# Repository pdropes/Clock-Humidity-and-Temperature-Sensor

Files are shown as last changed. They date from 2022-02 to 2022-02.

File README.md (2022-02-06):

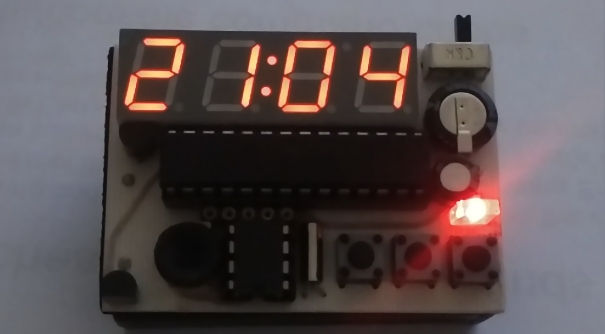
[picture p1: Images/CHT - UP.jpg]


# Clock, Humidity and Temperature Sensor
Relógio com medição de temperatura e humidade relativa

Descrição:
Pequeno aparelho portátil para visualização horária, temperatura e humidade relativa (alternadamente).
Já tinha trabalhado anteriormente com o sensor SHT21 da Sensirion, na construção de um controlador de estufa, é pequeno 3x3mm mas tem uma boa resolução (12/14bit for RH/T = RH0.04 & T0.01), apesar de fazer a leitura com esta precisão, uso aqui apenas uma casa decimal ás limitações do display.
Não foi implementado na programação medições de temperatura negativas, embora seja possível com outro tipo de display.
O sensor foi aqui montado numa placa á parte para minimizar a transferência térmica com a pcb principal (também sugerido na sua ficha técnica), entretanto a sua alimentação só é activada no momento das medições, reduz o consumo e tem maior precisão na leitura.
Desenho do circuito, fabrico da PCB, montagem e programação em 7 dias.

Caracteristicas:
- Microcontrolador atmega8 a 4MHz interno (não há necessidade de precisão aqui)
- Relógio RTC (PCF8563) com recurso a supercap 0.047F para retenção horária
- Possibilidade de acerto horário através dos switchs, modo ADC
- Sensor STH21 alimentado a 2.8V (VDD 2.1V to 3.6V), level shifter através de 2 BS170
- Consumo de 8 a 12mA (depende da intensidade do display)
- Brilho ajustável 

Programação: Bascom AVR, PCB: Eagle

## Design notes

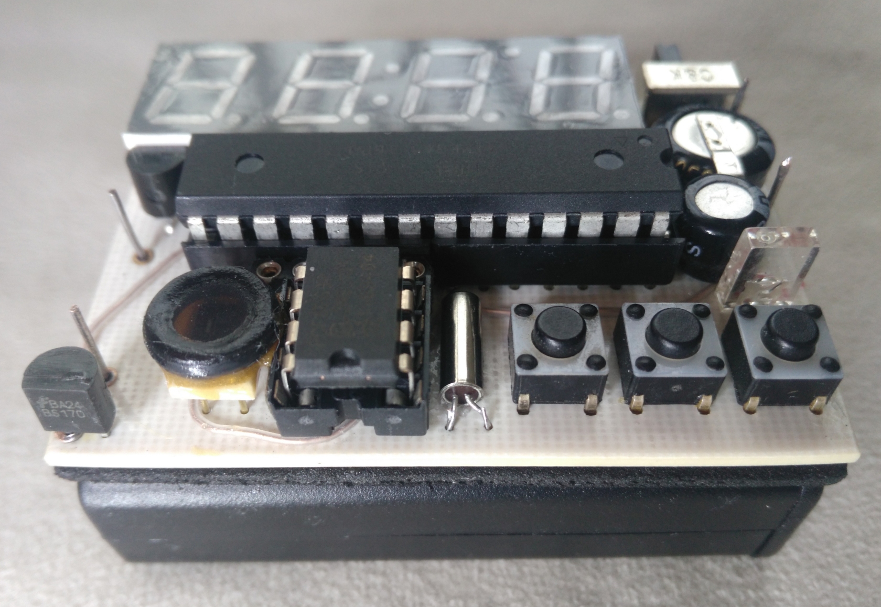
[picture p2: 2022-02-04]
Images/CTH - Filtro poeiras.jpg

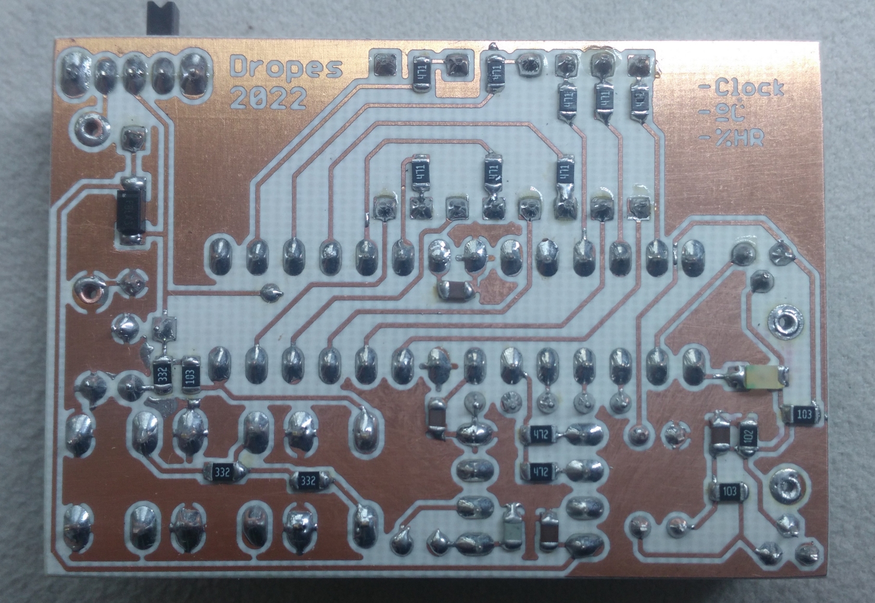
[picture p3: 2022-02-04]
Images/CTH - PCB SMDs.jpg

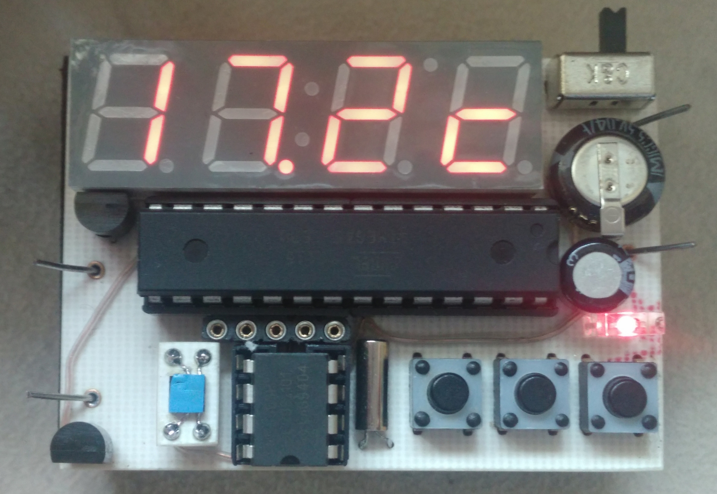
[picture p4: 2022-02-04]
Images/CTH - Funcionando.jpg

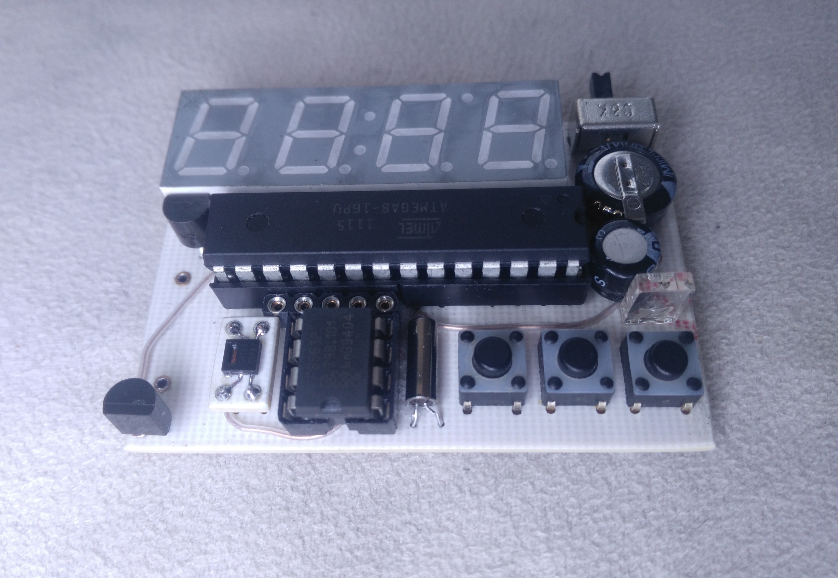
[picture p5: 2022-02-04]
Images/CTH - PCB TOP.jpg

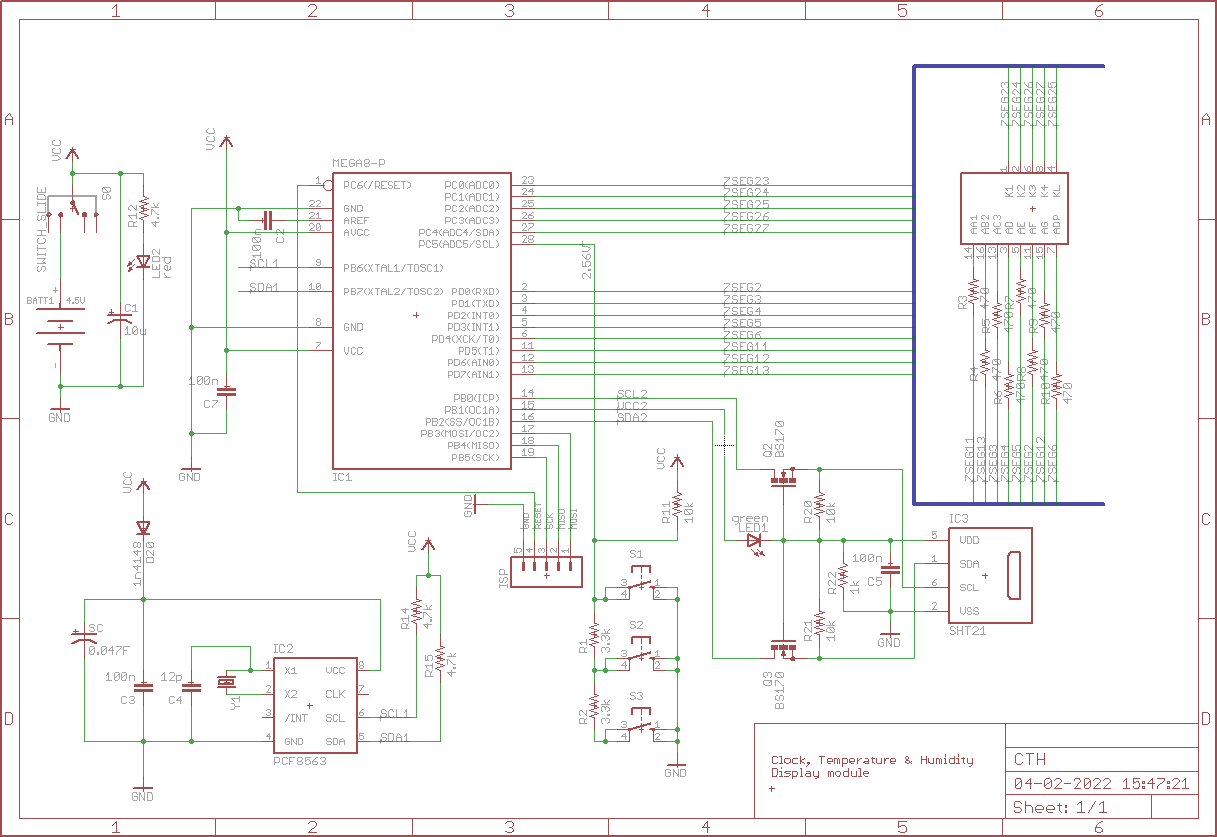
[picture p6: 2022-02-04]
Layout/CHT - Esquema.png

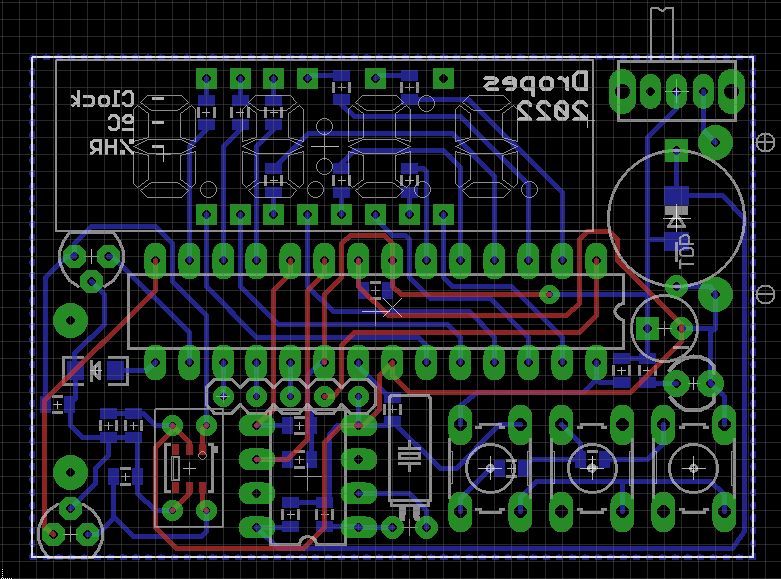
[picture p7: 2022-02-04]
Layout/CTH - PCB.png

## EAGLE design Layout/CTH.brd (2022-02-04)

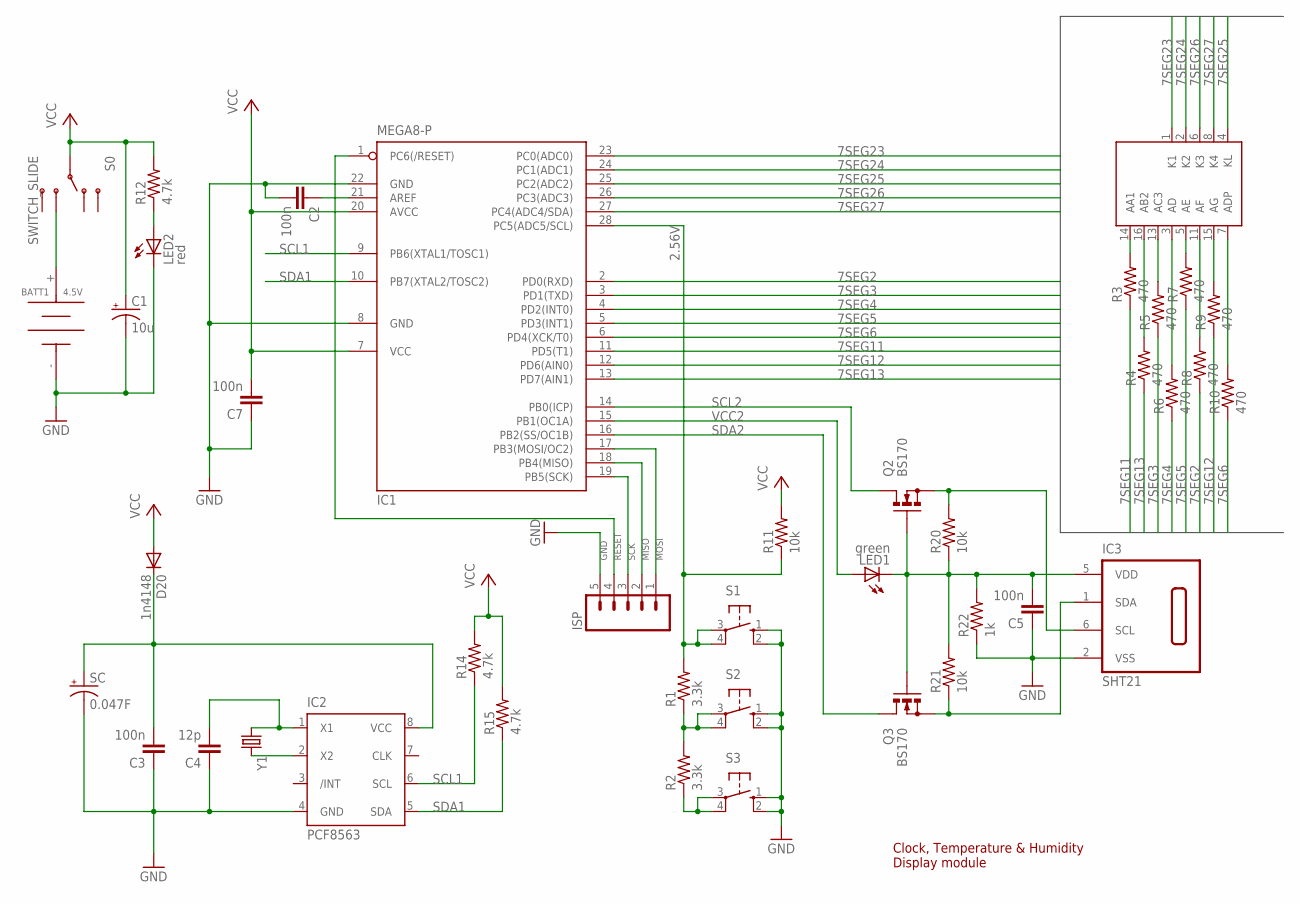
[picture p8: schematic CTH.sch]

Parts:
7SEG: LTC-4027JRLTC-4027JR; LTC-4727JR
BATT1: 1291-[2-56]; 1291
C1: 10u; CPOL-RADIAL-10UF-25V
C2, C3, C5, C7: 100n; 0805
C4: 12p; 0805
D20: 1n4148; SOD80C
IC1: MEGA8-P; DIL28-3
IC2: PCF8563; DS1307_PCF8583_DIL08
IC3: SHT21; DFN6/SHT
ISP: M05PTH; 1X05
LED1: green; SPARKFUN_LED-1206
LED2: red; LED3MM
Q2, Q3: BS170; SOT54E
R1, R2: 3.3k; 0805
R3, R4, R5, R6, R7, R8, R9, R10: 470; 0805
R11, R20, R21: 10k; 0805
R12, R14, R15: 4.7k; 0805
R22: 1k; 0805
S0: SWITCH_SLIDE
S1: 10-XX; B3F-10XX; MPN B3F-1000
S2, S3: 10-XX; B3F-10XX
SC: 0.047F; SUPERCAP_0.047F
Y1: CRYSTALTC38H; TC38H

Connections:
2.56V: IC1.28 (PC5(ADC5/SCL)), R1.2, R11.1, S1.3, S1.4 (P1)
7SEG2: IC1.2 (PD0(RXD)), R8.1
7SEG3: IC1.3 (PD1(TXD)), R5.1
7SEG4: IC1.4 (PD2(INT0)), R6.1
7SEG5: IC1.5 (PD3(INT1)), R7.1
7SEG6: IC1.6 (PD4(XCK/T0)), R10.1
7SEG11: IC1.11 (PD5(T1)), R3.1
7SEG12: IC1.12 (PD6(AIN0)), R9.1
7SEG13: IC1.13 (PD7(AIN1)), R4.1
7SEG23: 7SEG.1 (K1), IC1.23 (PC0(ADC0))
7SEG24: 7SEG.2 (K2), IC1.24 (PC1(ADC1))
7SEG25: 7SEG.4 (KL), IC1.25 (PC2(ADC2))
7SEG26: 7SEG.6 (K3), IC1.26 (PC3(ADC3))
7SEG27: 7SEG.8 (K4), IC1.27 (PC4(ADC4/SDA))
GND: BATT1.-, C1.2 (-), C2.2, C3.1, C4.1, C5.1, C7.1, IC1.8 (GND), IC1.22 (GND), IC2.4 (GND), IC3.2 (VSS), ISP.5, LED2.K (C), R22.1, S1.1 (S), S1.2 (S1), S2.1 (S), S2.2 (S1), S3.1 (S), S3.2 (S1), SC.2 (-)
MISO: IC1.18 (PB4(MISO)), ISP.2
MOSI: IC1.17 (PB3(MOSI/OC2)), ISP.1
unnamed: 7SEG.14 (AA1), R3.2
unnamed: 7SEG.16 (AB2), R4.2
unnamed: 7SEG.13 (AC3), R5.2
unnamed: BATT1.+, S0.E
unnamed: 7SEG.3 (AD), R6.2
unnamed: 7SEG.5 (AE), R7.2
unnamed: 7SEG.11 (AF), R8.2
unnamed: 7SEG.15 (AG), R9.2
unnamed: 7SEG.7 (ADP), R10.2
unnamed: IC2.2 (X2), Y1.2
unnamed: C2.1, IC1.21 (AREF)
unnamed: C5.2, IC3.5 (VDD), LED1.C, Q2.G, Q3.G, R20.1, R21.2, R22.2
unnamed: LED2.A, R12.1
unnamed: IC3.1 (SDA), Q3.S, R21.1
unnamed: R2.1, S3.3, S3.4 (P1)
unnamed: C4.2, IC2.1 (X1), Y1.1
unnamed: R1.1, R2.2, S2.3, S2.4 (P1)
unnamed: IC3.6 (SCL), Q2.S, R20.2
RESET: IC1.1 (PC6(/RESET)), ISP.4
SCK: IC1.19 (PB5(SCK)), ISP.3
SCL1: IC1.9 (PB6(XTAL1/TOSC1)), IC2.6 (SCL), R14.1
SCL2: IC1.14 (PB0(ICP)), Q2.D
SDA1: IC1.10 (PB7(XTAL2/TOSC2)), IC2.5 (SDA), R15.1
SDA2: IC1.16 (PB2(SS/OC1B)), Q3.D
VCC: C1.1 (+), C7.2, D20.A, IC1.7 (VCC), IC1.20 (AVCC), R11.2, R12.2, R14.2, R15.2, S0.M
VCC2: IC1.15 (PB1(OC1A)), LED1.A
VCC_RTC: C3.2, D20.C, IC2.8 (VCC), SC.1 (+)

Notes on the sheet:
Clock, Temperature & Humidity Display module

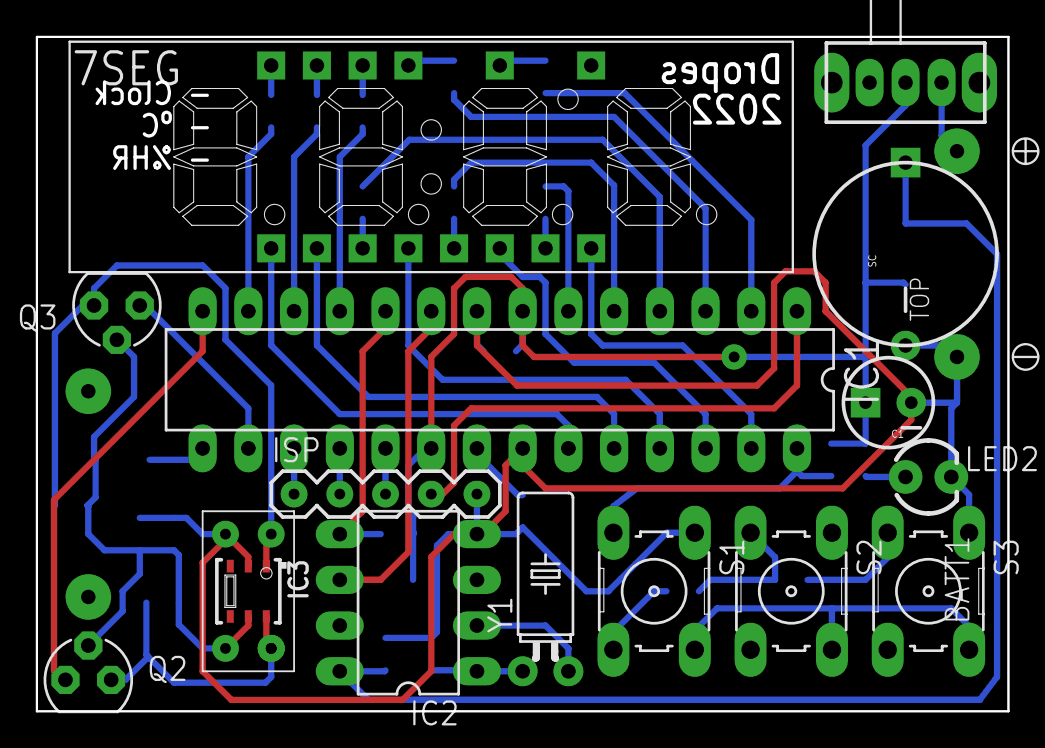
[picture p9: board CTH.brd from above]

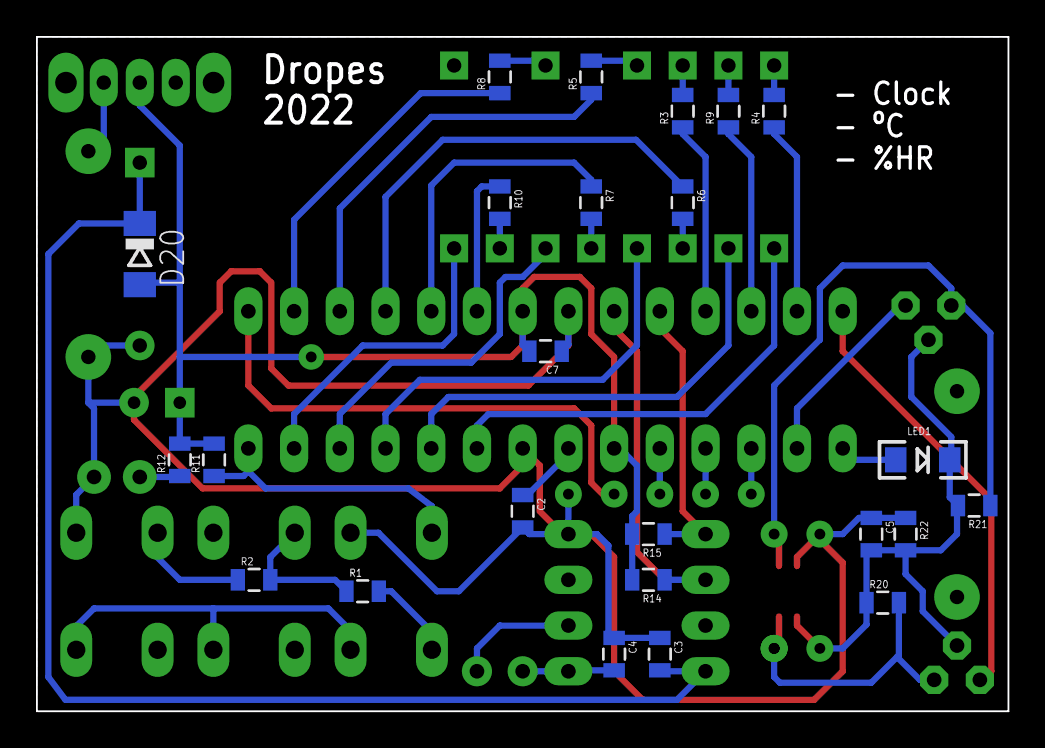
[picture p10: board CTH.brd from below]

Board: 2 copper layers, 54.0 x 37.5 mm, 40 parts (24 on the bottom side), 44 nets.

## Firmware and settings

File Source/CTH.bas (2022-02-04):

'#Dropes 02..03-02-2022
'clock - temperature - humidity
'Fuses: hfuse=D9 lfuse=E3

$regfile = "m8def.dat"
$crystal = 4000000

$hwstack = 32                                               ' default use 32 for the hardware stack
$swstack = 10                                               ' default use 10 for the SW stack
$framesize = 40                                             ' default use 40 for the frame space

'PIN        I/O   Func.      Func.
'09-PB6  O    SCL         RTC
'10-PB7  IO   SDA
'
'14.PB0  O    SCL2       SENSOR
'15.PB1  O    VCC2
'16.PB2  IO   SDA2

'23.PC0  O    7SEG_K1
'24.PC1  O    7SEG_K2
'25.PC2  O    7SEG_KL
'26.PC3  O    7SEG_K3
'27.PC4  O    7SEG_K4
'28.PC5  I      ADC5      SW1,2,3
'
'02.PD0  O     7SEG_F
'03.PD1  O     7SEG_C3
'04.PD2  O     7SEG_D
'05.PD3  O     7SEG_E
'06.PD4  O     7SEG_DP
'11.PD5  O     7SEG_A1
'12.PD6  O     7SEG_G
'13.PD7  O     7SEG_B2

'Digit nº
Ddrc = &B11011111
Portc = &B11011111
W1 Alias Portc.4
W2 Alias Portc.3
Col Alias Portc.2
W3 Alias Portc.1
W4 Alias Portc.0

'Segment
Ddrd = &B11111111
Portd = &B0

'I2C
Config Scl = Portb.6
Config Sda = Portb.7
Config I2cdelay = 10
I2cinit

'SHT21
Sht_on Alias Portb.1
Sht_sda_o Alias Portb.2
Sht_sda_i Alias Pinb.2
Sht_scl Alias Portb.0
Config Sht_on = Output
Config Sht_sda_o = Output
Config Sht_scl = Output

'3 SW  Open=1023 S1=0 S2=423 S3=678
Config Adc = Single , Prescaler = 8 , Reference = Internal
Enable Adc

'8 -bit Timer / Counter0
'Prescale:1,8,64,256 or 1024
Config Timer0 = Timer , Prescale = 64 , Clear Timer = 1
Enable Ovf0
On Ovf0 Show_time , Saveall
Disable Interrupts

'CLOCK:
Dim Dis As Byte
Dim Mem(4) As Byte
Dim Time_flag As Boolean

Dim Col_off As Integer
Dim Old_s As Byte

Dim S , Sh , Sl As Byte
Dim M , Mh , Ml As Byte
Dim H , Hh , Hl As Byte

Dim Sdec , Mdec , Hdec As Byte
Dim M_chk , H_chk As Boolean
Dim Sbcd , Mbcd , Hbcd As Byte

Dim Light As Byte

Dim Clock_timeout As Byte
Dim Key As Byte
Dim Tmp As Byte

Dim Value As Word

'SHT21:
Dim Clock_mode As Boolean
Dim Dot3 As Byte
Dim Unit As Byte
Dim Command As Byte

Dim Tecal As Single
Dim Sensor_result As Word
Dim Tempres As String * 6

Dim Rhcal As Single
Dim Rhres As String * 6

Dim Sensor_round As Word
Dim N_pos As Byte

Dim Data_l As Byte
Dim Data_h As Byte

Declare Sub Get_time
Declare Sub Register_time
Declare Sub Set_clock
Declare Function Get_key As Byte
Declare Sub Get_sensor
Declare Sub Display_sensor

'---------------------------------------MAIN----------------------------------------------
Call Get_time
Enable Interrupts

Do
    Clock_mode = 0                                          '0=timer, 1=Temperature, 2=Humidity

    Time_flag = 0                                           'evita glitches com a interrupção Timer0
    While Time_flag = 0
    Wend
    Call Get_time

    If Get_key() = 1 Then Call Set_clock
    If Get_key() = 2 And Light > 0 Then Light = Light -1
    If Get_key() = 3 And Light < 150 Then Light = Light + 1

    If Clock_timeout = 5 Then
        Clock_timeout = 0
        Call Display_sensor
    End If
Loop

'-------------------------------------------------------------------------------------------
Sub Set_clock
    H_chk = 1                                               'aumenta o brilho do nº a ser ajustado

    While Get_key() = 1
        Col_off = 0
        Waitms 20
    Wend
    While Get_key() <> 0
        Waitms 20
    Wend

    While Get_key() <> 1
        Col_off = 0
        Key = Get_key()
        Select Case Key
            Case 3:
                If Hdec < 23 Then Hdec = Hdec + 1 Else Hdec = 0
                H = Hdec
                M = Mdec
                Call Register_time
                Call Get_time
                Waitms 150
            Case 2:
                If Hdec > 0 Then Hdec = Hdec - 1 Else Hdec = 23
                H = Hdec
                M = Mdec
                Call Register_time
                Call Get_time
                Waitms 150
        End Select
    Wend

    H_chk = 0
    M_chk = 1
    Waitms 20

    While Get_key() = 1
        Col_off = 0
        Waitms 20
    Wend

    While Get_key() <> 1
        Col_off = 0
        Key = Get_key()
        Select Case Key
            Case 3:
                If Mdec < 59 Then Mdec = Mdec + 1 Else Mdec = 0
                H = Hdec
                M = Mdec
                Call Register_time
                Call Get_time
                Waitms 150
            Case 2:
                If Mdec > 0 Then Mdec = Mdec - 1 Else Mdec = 59
                H = Hdec
                M = Mdec
                Call Register_time
                Call Get_time
                Waitms 150
        End Select
    Wend

    M_chk = 0
    While Get_key() <> 0
        Waitms 20
    Wend
End Sub

'-------------------------------------------------------------------------------------------
Sub Get_time
   'I2c
   'Pcf8563
    I2cstart
    I2cwbyte &HA2
    I2cwbyte 8
    I2cwbyte 0
    I2cstop
    I2cstart
    I2cwbyte &HA2
    I2cwbyte 2
    I2cstart
    I2cwbyte &HA3
    I2crbyte S , Ack
    I2crbyte M , Ack
    I2crbyte H , Nack
    I2cstop

    'só é usada a variável S para Col
    Sdec = Makedec(s)
    Sl = S And &HF
    Sh = S And &H70
    Swap Sh

    Mdec = Makedec(m)
    Ml = M And &HF
    Mh = M And &H70
    Swap Mh

    Hdec = Makedec(h)
    Hl = H And &HF
    Hh = H And &H30
    Swap Hh

    Mem(1) = Ml
    Mem(2) = Mh
    Mem(3) = Hl
    Mem(4) = Hh
End Sub

'-------------------------------------------------------------------------------------------
Sub Register_time
    S = 0
    Sbcd = Makebcd(s)
    Mbcd = Makebcd(m)
    Hbcd = Makebcd(h)

    I2cstart
    I2cwbyte &HA2
    I2cwbyte 0
    I2cwbyte 8
    I2cstart
    I2cwbyte &HA2
    I2cwbyte 2
    I2cwbyte Sbcd
    I2cwbyte Mbcd
    I2cwbyte Hbcd
    I2cstop
End Sub

'-------------------------------------------------------------------------------------------
'Uso de variável temporária, dá erro ao atribuir vários valores á mesma função
Function Get_key
    Disable Ovf0
    Value = Getadc(5)
    If Value > 1000 Then Tmp = 0
    If Value < 50 Then Tmp = 1
    If Value > 50 And Value < 500 Then Tmp = 2
    If Value > 500 And Value < 1000 Then Tmp = 3
    Get_key = Tmp
    Enable Ovf0
End Function
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

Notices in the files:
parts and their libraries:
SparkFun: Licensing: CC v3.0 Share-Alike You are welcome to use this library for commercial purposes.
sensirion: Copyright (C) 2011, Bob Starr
